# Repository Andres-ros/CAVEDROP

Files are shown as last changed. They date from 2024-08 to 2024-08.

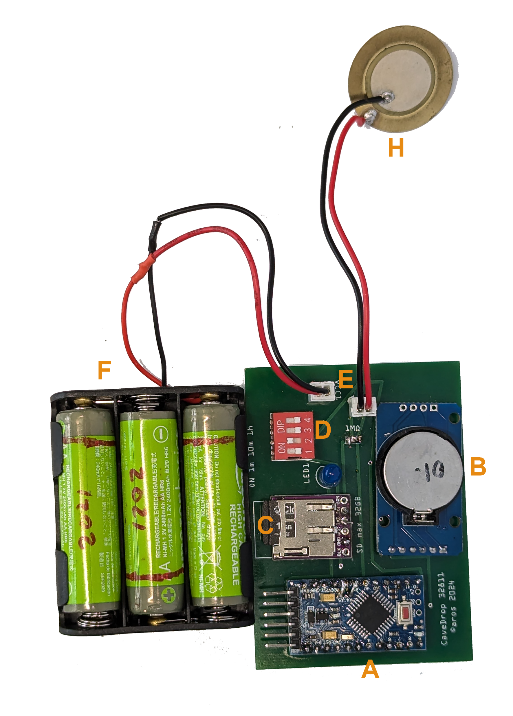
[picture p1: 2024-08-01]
CAVEDROP-EQUIPO01.png

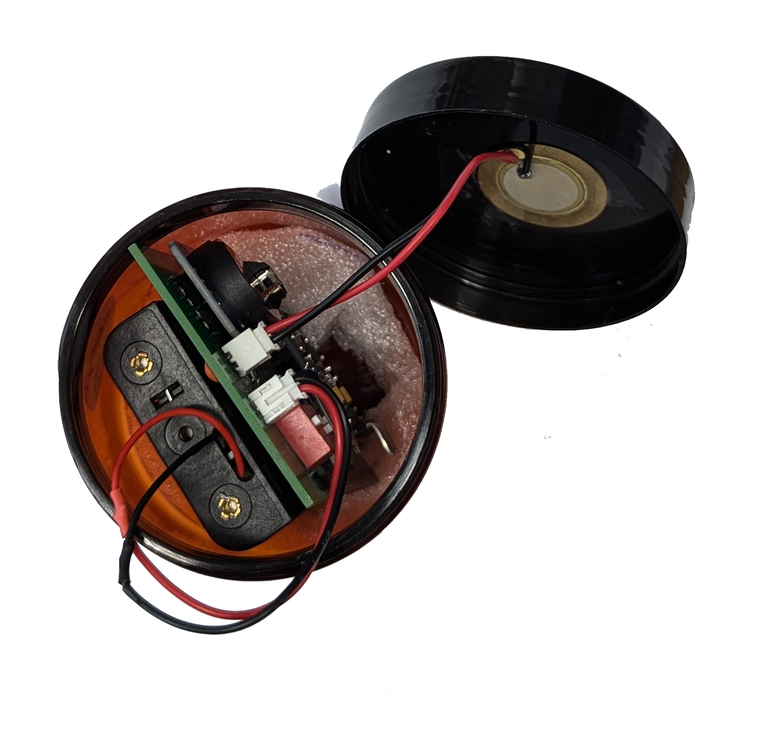
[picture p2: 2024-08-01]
CAVEDROP005.png

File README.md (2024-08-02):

# Drop counter CAVEDROP
Drop counter for speleothems in caves
CAVEDROP
Andrés Ros
CaveDrop is an autonomous system designed to monitor the drip rate in caves, specifically those contributing to the formation of speleothems. This system uses piezoelectric sensors to detect and record drop impacts, allowing researchers to collect valuable data on the frequency and distribution of these drops over various periods. CaveDrop is a solution designed for speleological studies that quantifies the number of drops impacting a surface over time. These data are crucial for understanding the processes of speleothem formation and for evaluating environmental conditions within caves.
The hardware configuration uses only the necessary and minimal elements to optimize power consumption and final cost. It includes a low-power ATmega328 pro mini microcontroller based on the enhanced RISC architecture of AVR®, a piezoelectric sensor, several switches to adjust the data logging interval (1 minute, 10 minutes, or 1 hour), and a temporary data storage system in a buffer before cyclically transferring it to a removable microSD card. The device's software counts the detected drops, avoids false positives with a 0.2-second delay, and stores the data in TXT format for further analysis. All the hardware is housed inside a waterproof container, designed to operate in the often humid and adverse conditions of caves...
02/08/2024 Modification of DS3231 module to optimize consumption see image Modif_DS3231.jpg

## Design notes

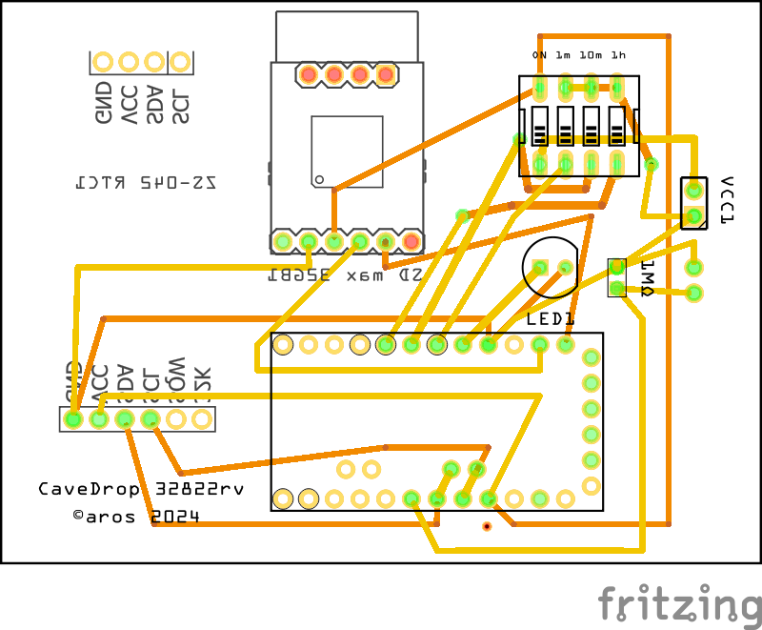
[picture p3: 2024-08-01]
CAVEDROP_32822RV2_pcb.png

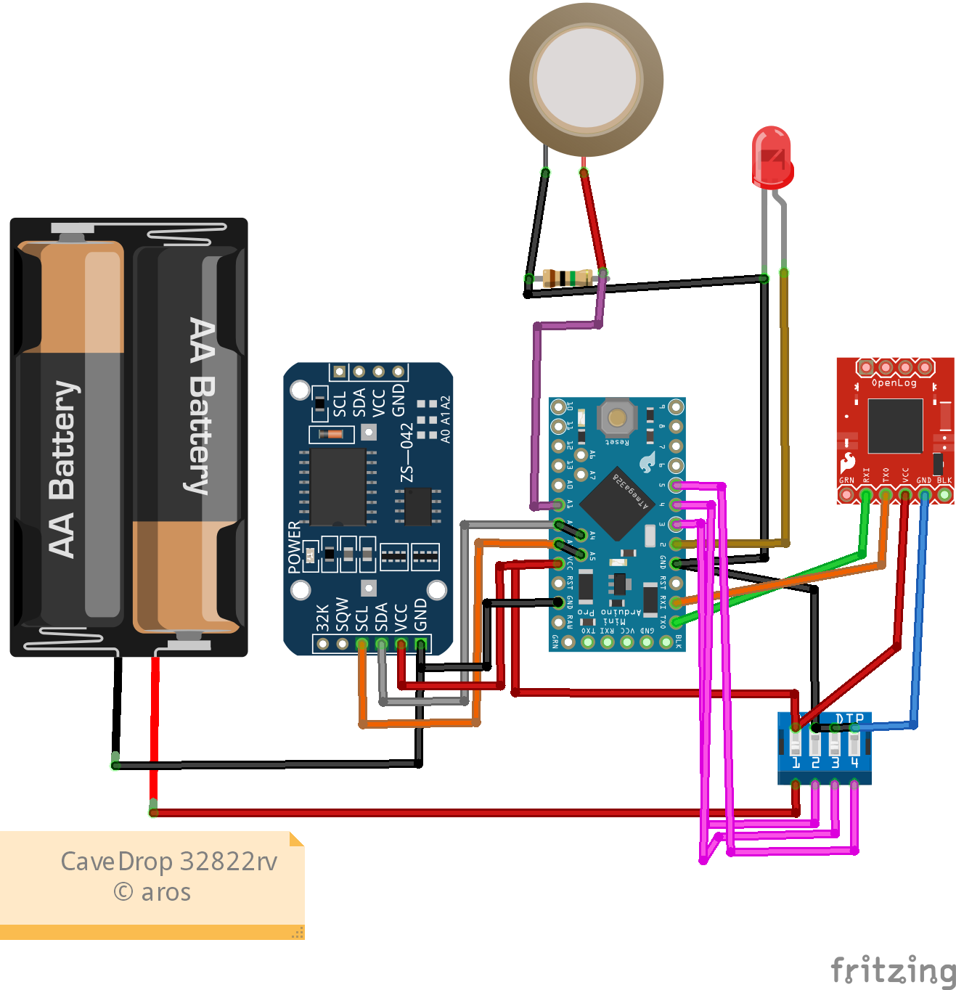
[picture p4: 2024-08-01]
CAVEDROP_32822RV2_bb.png

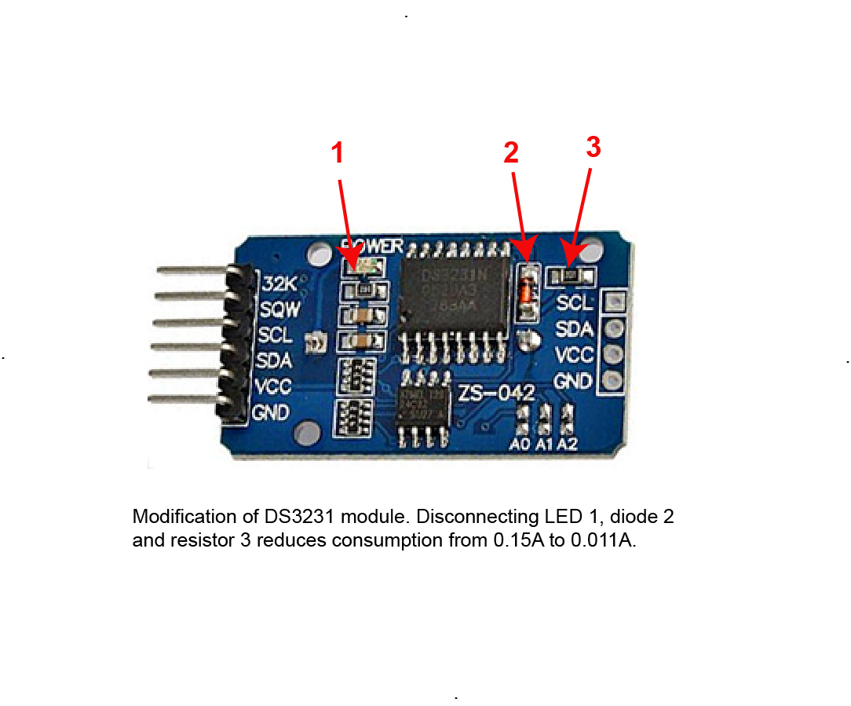
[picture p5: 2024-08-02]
Modif_DS3231.jpg

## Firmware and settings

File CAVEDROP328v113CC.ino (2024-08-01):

// CAVEDROP v113CC
// Andrés Ros julio 2024
// Bajo licencia Creative Commons CC BY-NC-SA 4.0
// sistema para la detección de impactos, utilizado como contador de gotas en espeleotemas de cavidades
// Se puede programar por medio de interruptores el total de gotas por minutos, cada 10 minutos o 1 hora
// materiales: Atmega328PB Pro Mini, modulo reloj DS3231, Sensor piezoelectrico, OpenLog mini SD, DIP 4 , Baterias AA x3, resistencia 1M, led.
// El sensor piezoelectrico detecta los impactos que son procesados en el Atmega328PB generando un registro con fecha, hora:minuto, total gotas periodo tiempo seleccionado (1mn, 10mn, 1h).
// La sesiblidad del sensor piezoelectrico puede ser ajustada.
// Se incluye la libreria SoftwareSerial.h para desvincular los pines Xt y RX para no interferir entre OpenLog y cargas o revisiones del programa
// Un buffer almacena registros y los vuelca periodicamente al OpenLog.
// Mi agradecimiento a los trabajos de E.K. Mallon 

#include <Wire.h>
#include <RTClib.h>
#include <SoftwareSerial.h>

// Define los pines
#define LED_PIN 2       // Pin para el LED
#define piezoPin A1     // Pin para el sensor piezoeléctrico en un pin analógico
#define SWITCH_PIN_1 3  // Pin para el interruptor de 1 minuto
#define SWITCH_PIN_10 4 // Pin para el interruptor de 10 minutos
#define SWITCH_PIN_60 5 // Pin para el interruptor de 1 hora

#define BUFFER_SIZE 10  // Tamaño del buffer para almacenar registros de gotas

RTC_DS3231 rtc;  // Crea una instancia del RTC
SoftwareSerial mySerial(10, 11); // Configura SoftwareSerial en los pines 10 y 11 RX, TX

int gotasContador = 0;
unsigned long lastImpactTime = 0;
const unsigned long impactCooldown = 300; // Tiempo mínimo entre impactos para evitar falsos positivos
unsigned long lastCheckTime = 0;
unsigned long tiempoRegistro = 60000; // Tiempo de registro inicial en milisegundos (1 minuto)

char buffer[BUFFER_SIZE][64];
int bufferIndex = 0;

// Variables para el filtro de paso bajo
float filteredValue = 0;
const float alpha = 0.1;  // Coeficiente de suavizado para el filtro

// Variables para medir el voltaje, para mantner la hora aúnque se descarge la bateria principal
const int batteryPin = A0; // Pin analógico para medir el voltaje de la batería
const float referenceVoltage = 5.0; // Voltaje de referencia del Arduino
const float dividerRatio = 2.0; // Ratio del divisor de voltaje

void setup() {
  Serial.begin(9600); // Comunicación para monitoreo y OpenLog
  mySerial.begin(9600); // Inicia SoftwareSerial para otra comunicación si es necesario

  pinMode(piezoPin, INPUT);
  pinMode(LED_PIN, OUTPUT);
  pinMode(SWITCH_PIN_1, INPUT_PULLUP);
  pinMode(SWITCH_PIN_10, INPUT_PULLUP);
  pinMode(SWITCH_PIN_60, INPUT_PULLUP);

  Wire.begin();
  if (!rtc.begin()) {
    Serial.println("No se pudo encontrar el módulo RTC");
    while (1); // Detiene el programa si no se encuentra el RTC
  }

  // Leer la hora actual del RTC al iniciar,revisa la hora para no perderla
  DateTime now = rtc.now();
  Serial.print("Fecha y hora actuales: ");
  Serial.print(now.year(), DEC);
  Serial.print('/');
  Serial.print(now.month(), DEC);
  Serial.print('/');
  Serial.print(now.day(), DEC);
  Serial.print(" ");
  Serial.print(now.hour(), DEC);
  Serial.print(':');
  Serial.print(now.minute(), DEC);
  Serial.print(':');
  Serial.print(now.second(), DEC);
  Serial.println();

  // comentar esta linea una vez cargado el programa y registrada la hora
  // volver a cargar el programa una vez sincronizada la hora con la linea comentada, para evitar buscar la sincornizacion hora, cada vez que se reinicie
 rtc.adjust(DateTime(F(__DATE__), F(__TIME__))); // Ajusta la hora del RTC al momento de la compilación

  delay(2000); // Esperar para asegurarse de que todo esté listo

  // Comandos para configurar el archivo de registro
  Serial.println("new RegistroGotas.txt"); // Crea un nuevo archivo si no existe
  delay(100);
  Serial.println("append RegistroGotas.txt"); // Añade datos al final del archivo
  delay(100);

  // Escribir la cabecera en el archivo CSV
  Serial.println("CaveDrop 328");
  delay(100);
  Serial.println("v113CC_002"); // se añade el numero de unidad para individualizar
  delay(100);
  Serial.println("Fecha, hora, gotas");
  delay(100);

  lastCheckTime = millis();
}

void loop() {
  int piezoValue = analogRead(piezoPin);
  filteredValue = alpha * piezoValue + (1 - alpha) * filteredValue; // Aplicar filtro de paso bajo

// ajuste sensibiidad piezolectrico
  if (filteredValue > 15 && millis() - lastImpactTime > impactCooldown) { 
    digitalWrite(LED_PIN, HIGH);
    gotasContador++;
    lastImpactTime = millis();
    delay(100);
    digitalWrite(LED_PIN, LOW);
  }

  // Verificar los estados de los interruptores y ajustar el tiempo de registro
  if (digitalRead(SWITCH_PIN_1) == LOW) {
    tiempoRegistro = 60000; // 1 minuto
  } else if (digitalRead(SWITCH_PIN_10) == LOW) {
    tiempoRegistro = 600000; // 10 minutos
  } else if (digitalRead(SWITCH_PIN_60) == LOW) {
    tiempoRegistro = 3600000; // 1 hora
  }

  if (millis() - lastCheckTime >= tiempoRegistro) {
    registrarGota(gotasContador);
    gotasContador = 0;
    lastCheckTime = millis();
    descargarBuffer();
  }
}

void registrarGota(int contador) {
  DateTime now = rtc.now();
  snprintf(buffer[bufferIndex], sizeof(buffer[bufferIndex]), "%04u-%02u-%02u,%02u:%02u,%d", 
           now.year(), now.month(), now.day(), now.hour(), now.minute(), contador);
  bufferIndex++;
  if (bufferIndex >= BUFFER_SIZE) {
    bufferIndex = 0; // Resetear el índice si se llena el buffer
  }
}

void descargarBuffer() {
  for (int i = 0; i < bufferIndex; i++) {
    Serial.println(buffer[i]); // Enviar al OpenLog y asegurar que cada registro esté en una nueva línea
  }
  bufferIndex = 0; // Reiniciar el índice del buffer después de descargar
}
